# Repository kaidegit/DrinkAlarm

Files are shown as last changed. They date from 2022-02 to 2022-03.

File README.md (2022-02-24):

# 提醒喝水器

本项目致力于复刻[何同学视频](https://www.bilibili.com/video/BV1244y1p7kt)中的智能杯垫，并添加更多的功能。~~才不是因为何同学做的开灯方案太没意义呢~~

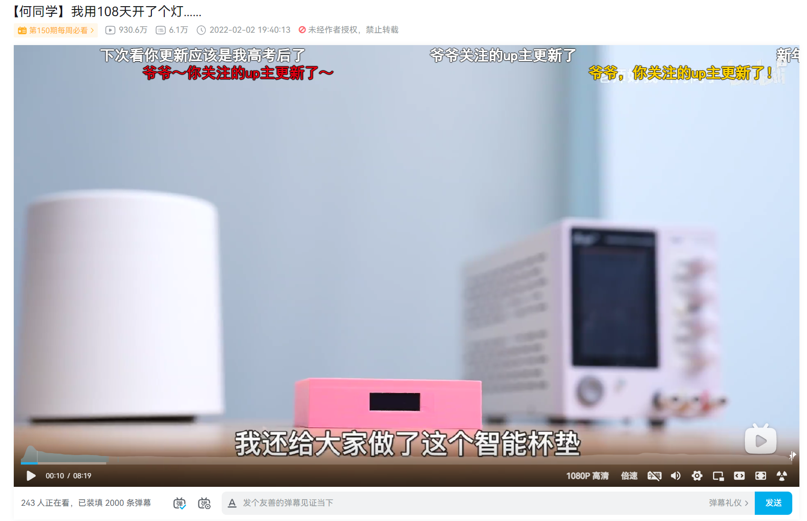
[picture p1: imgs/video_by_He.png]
video_by_He


## 方案设计

* 主芯片使用乐鑫ESP32，能在提供足够的性能的同时提供一个够用的互联网连接

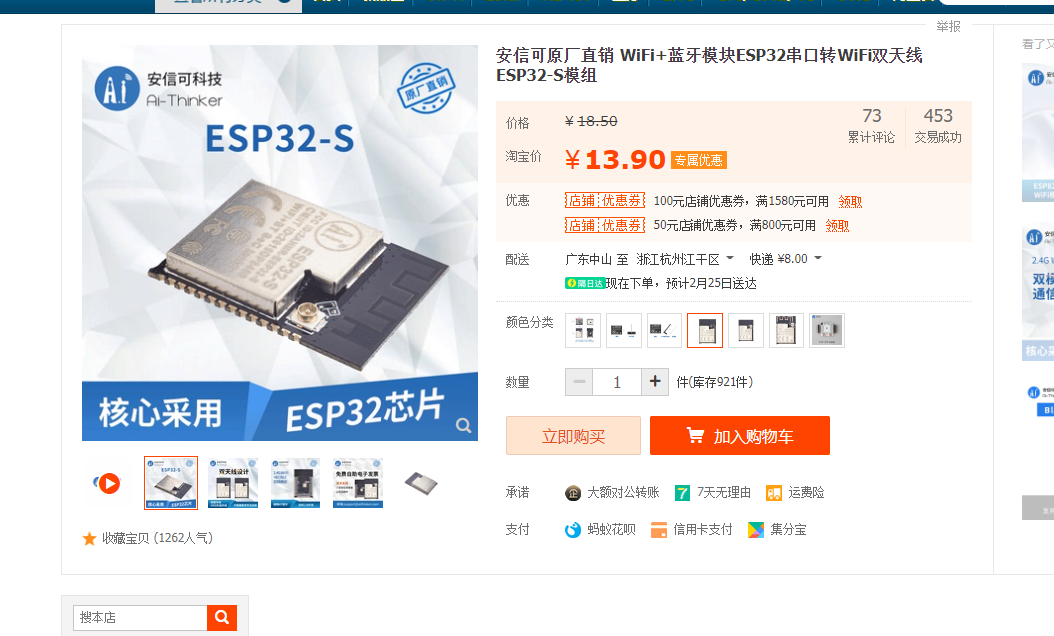
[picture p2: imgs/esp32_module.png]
esp32_module


* 检测杯子存在采用光电传感器，价格低廉，识别准确，美中不足需要在外壳上开孔

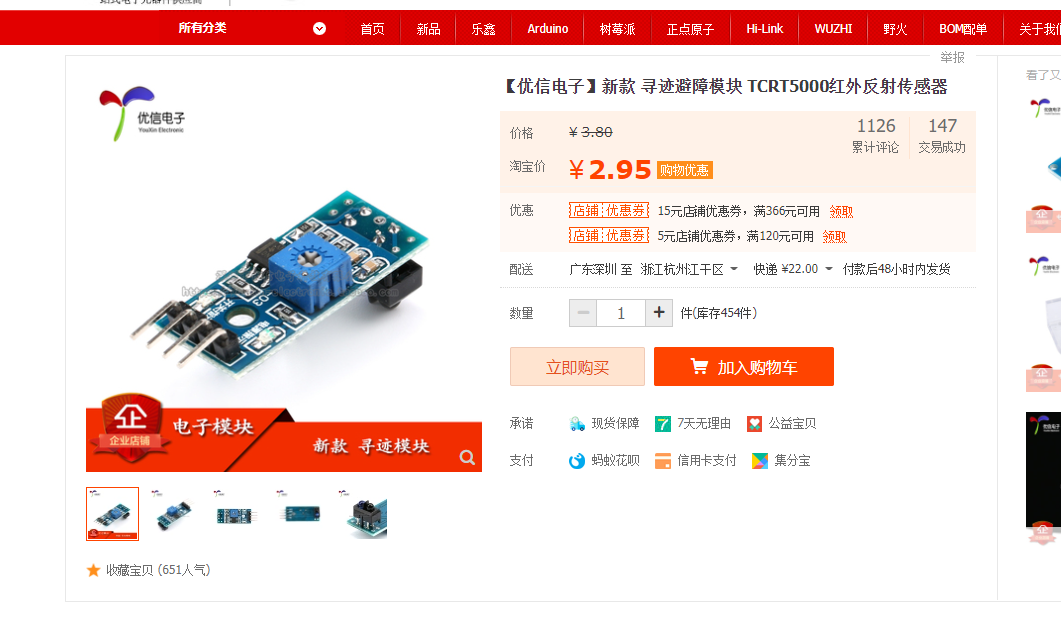
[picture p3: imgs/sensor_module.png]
sensor_module


* 提醒方案采用[Server酱](https://sct.ftqq.com/)的微信推送，同时板载蜂鸣器，可自行修改代码使用

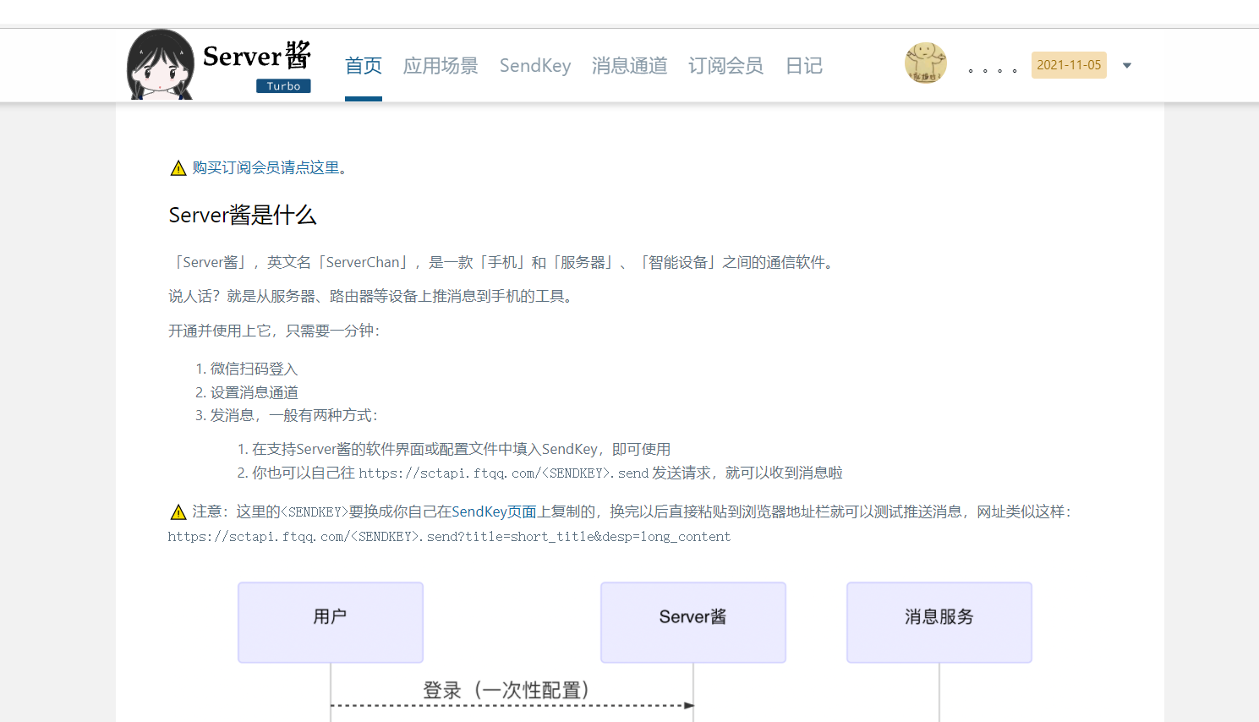
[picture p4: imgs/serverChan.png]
serverChan


* 外壳采用PETG打印而成，可自行选择其他材料以适应盛放开水的杯子

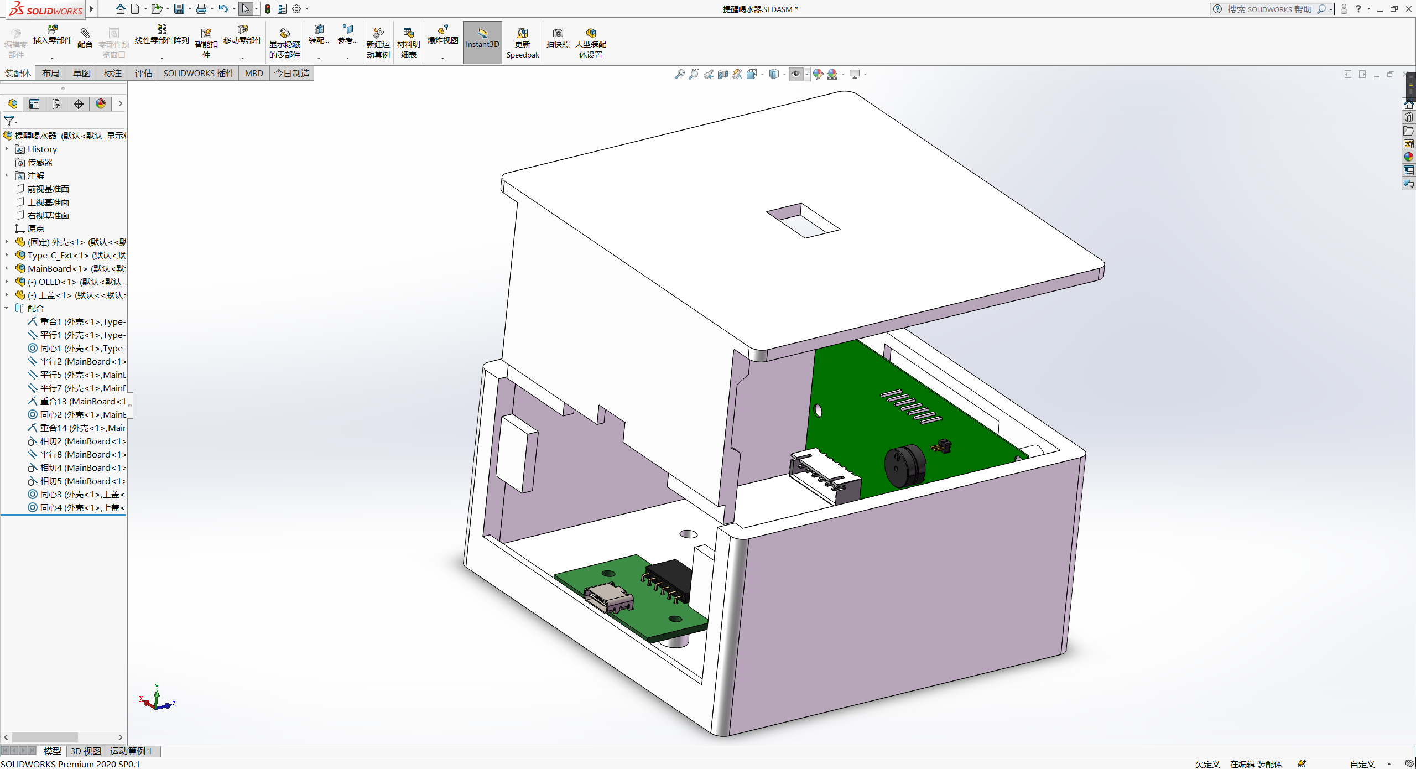
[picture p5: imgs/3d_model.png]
3d_model


## PCB设计

PCB使用Altium Designer和KiCAD设计。由于前后距离略长，PCB分为两块，一块为Type-C小板，一块为主PCB，两者通过杜邦线相连。推荐使用XH2.54系列端子以避免潜在的接触不良。推荐使用长度10或15厘米的线材。

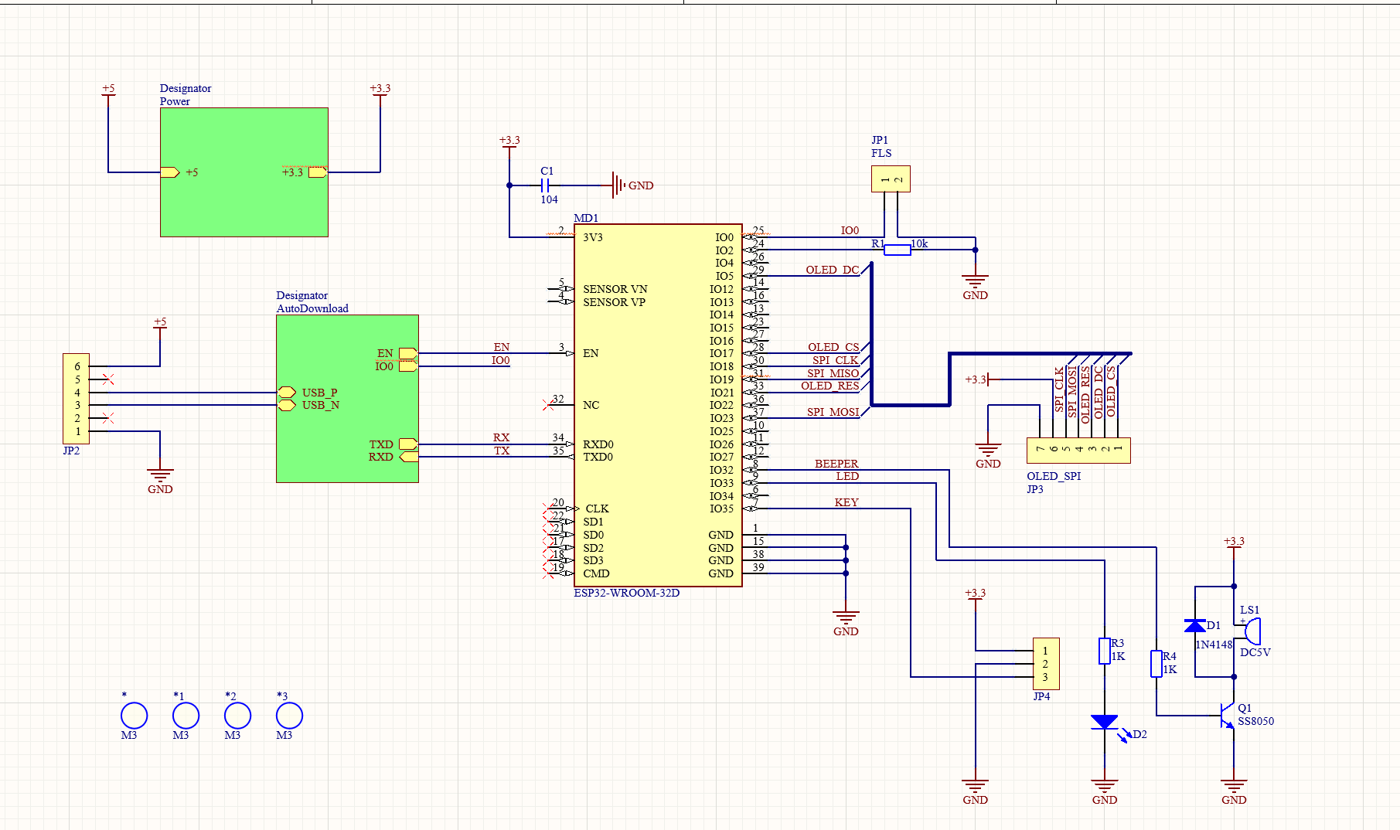
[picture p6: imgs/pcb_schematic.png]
pcb_schematic


## 外壳设计

外壳使用SoildWorks设计（大版本2020）。设计了上盖和底壳，两者通过长螺丝连接。长螺丝推荐使用M3 45mm，其他螺丝推荐使用M3 5mm。对于外壳的修改意见，欢迎提交issue和PR。

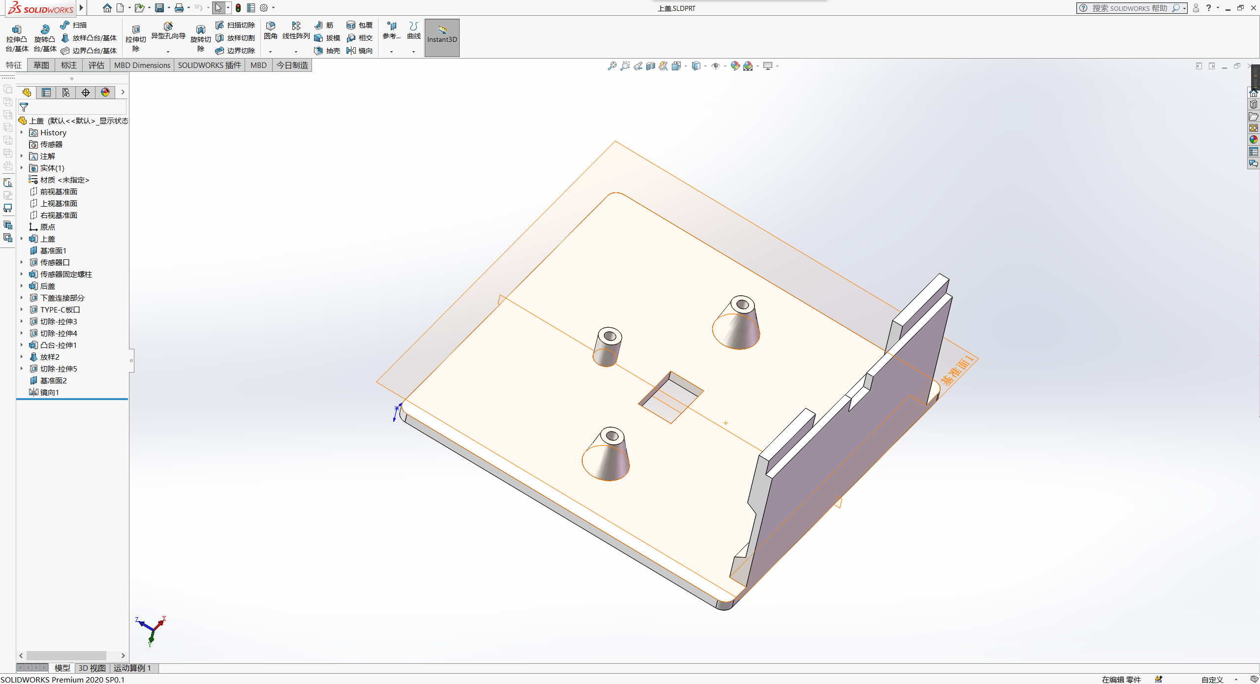
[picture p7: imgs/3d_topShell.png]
3d_topShell


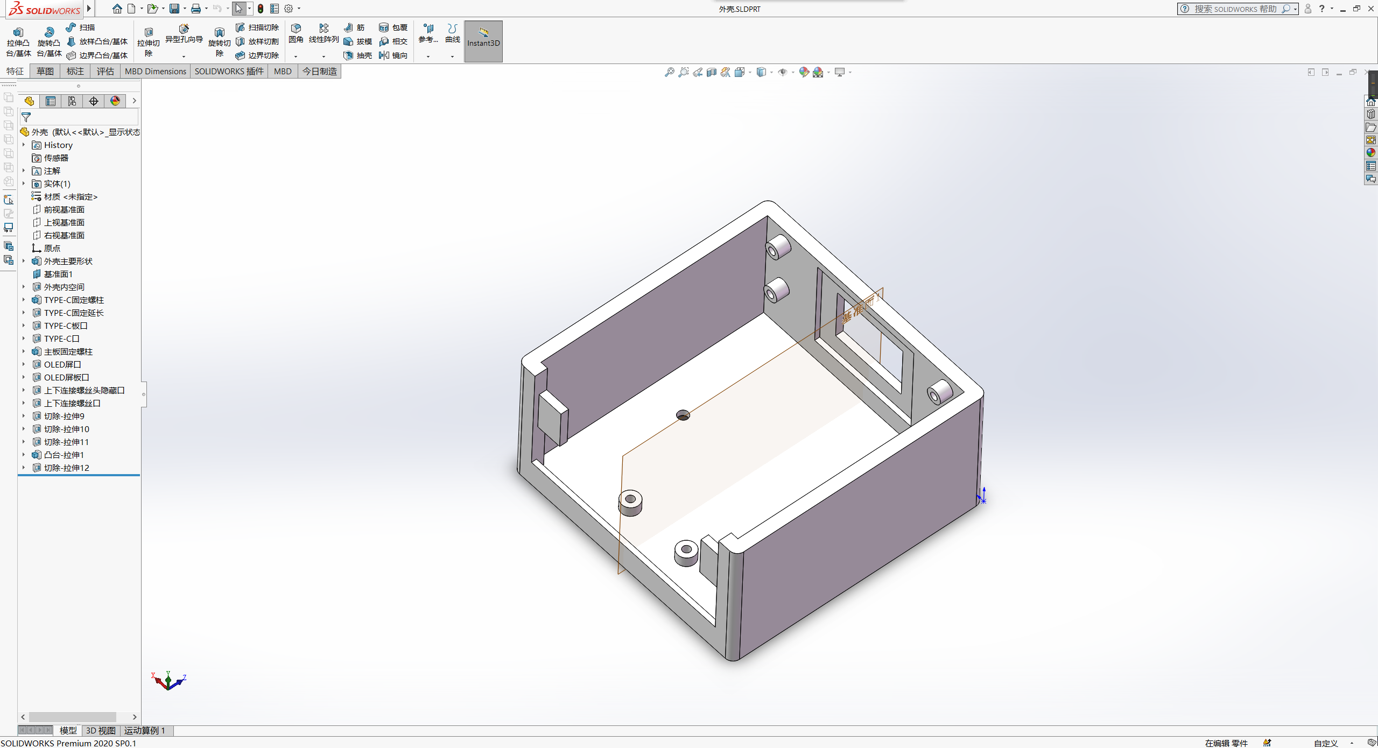
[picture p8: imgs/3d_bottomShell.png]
3d_bottomShell


## 程序设计

程序基于ESP-IDF框架，并使用Arduino as a ESP-IDF component。预计后期将移除。

程序主要功能为设定报警时间，获取联网信息，获取在线时间并显示，计时杯子存在时间并推送等。

主要流程如下：

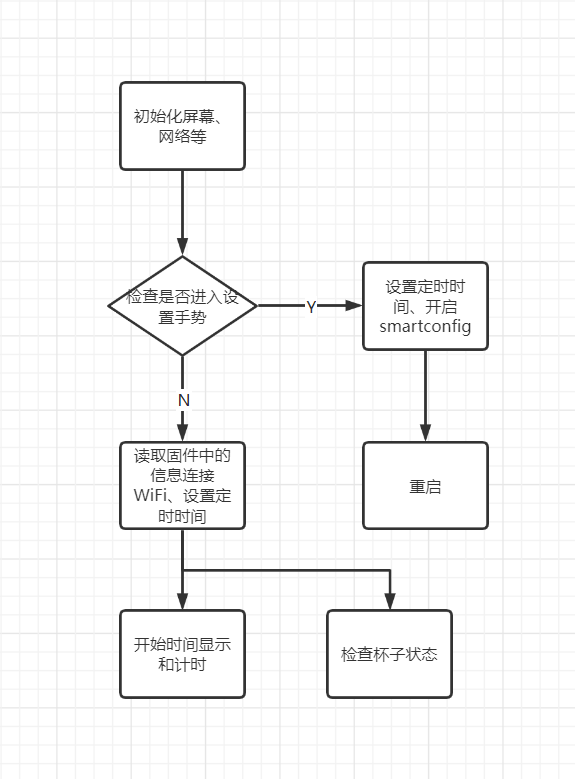
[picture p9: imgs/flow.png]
flow


## 效果图

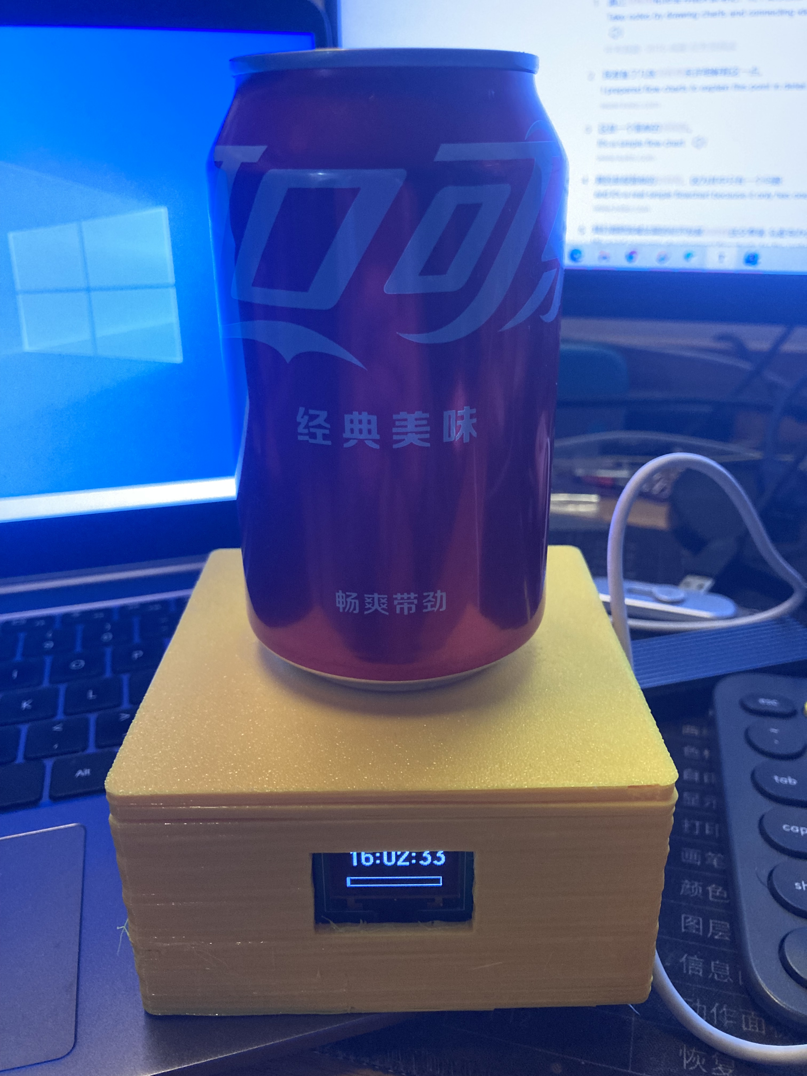
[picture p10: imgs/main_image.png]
main_image


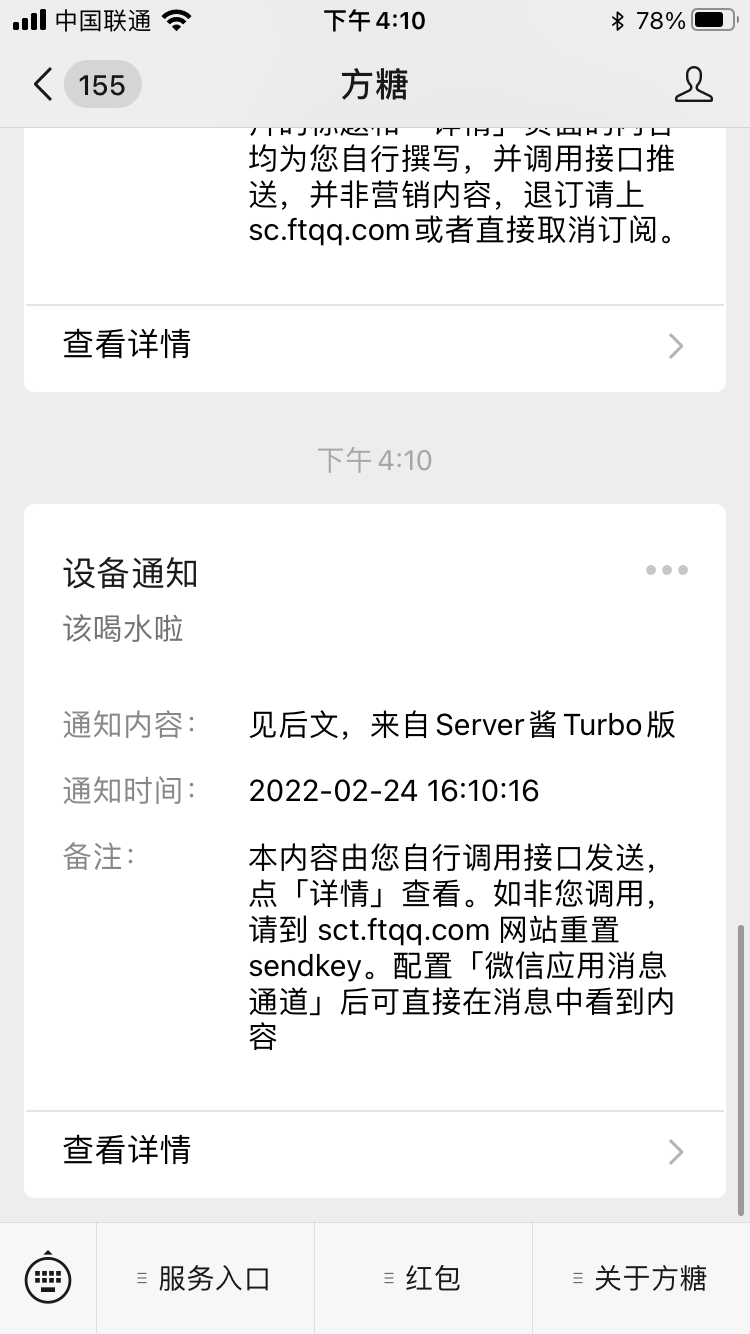
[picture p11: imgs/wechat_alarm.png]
wechat_alarm


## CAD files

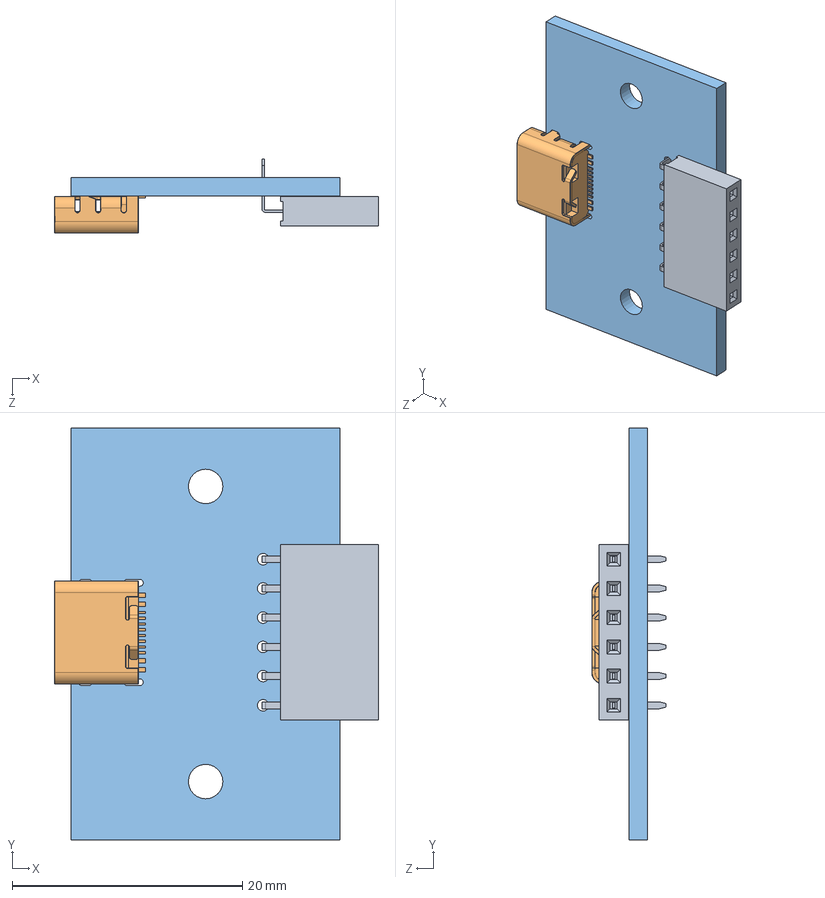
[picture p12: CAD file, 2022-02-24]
3DModel/Type-C_Ext.SLDASM
28.2 x 35.8 x 6.47 mm
SOLID^PinSocket_1x06_P2.54mm_Horizontal_Type-C_Ext(2)_Type-C_Ext
COMPOUND^Type-C_16Pin_ThroughtHole_Type-C_Ext(2)_Type-C_Ext
Type-C_Ext PCB^Type-C_Ext(2)_Type-C_Ext

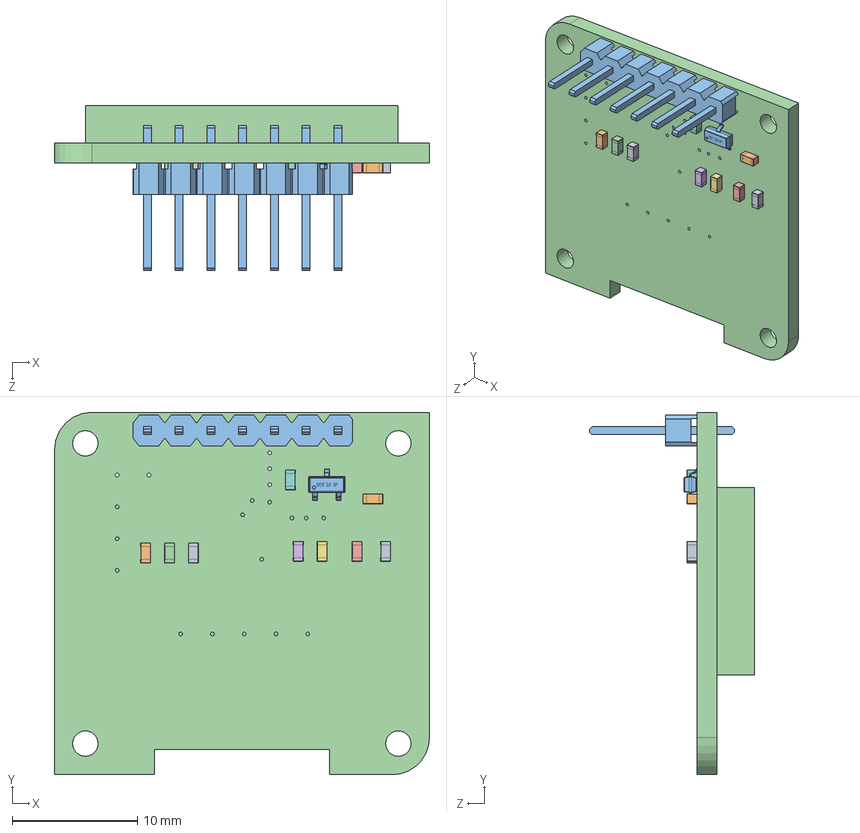
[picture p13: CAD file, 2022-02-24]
3DModel/OLED.SLDASM
30.0 x 29.0 x 13.2 mm
=_[0_1_1_5]^R0603_R5(2)_3D_PCB_7针SPI_2022-02-05_2022-02-05(2)_OLED
=_[0_1_1_5]^R0603_R6(2)_3D_PCB_7针SPI_2022-02-05_2022-02-05(2)_OLED
=_[0_1_1_10]^HDR-M-2.54_1X7_J1_3D_PCB_7针SPI_2022-02-05_2022-02-05(2)_OLED
=_[0_1_1_14]^C0603_C5(2)_3D_PCB_7针SPI_2022-02-05_2022-02-05(2)_OLED
=_[0_1_1_14]^C0603_C2(2)_3D_PCB_7针SPI_2022-02-05_2022-02-05(2)_OLED
=_[0_1_1_14]^C0603_C3(2)_3D_PCB_7针SPI_2022-02-05_2022-02-05(2)_OLED
=_[0_1_1_14]^C0603_C4(2)_3D_PCB_7针SPI_2022-02-05_2022-02-05(2)_OLED
=_[0_1_1_14]^C0603_C7(2)_3D_PCB_7针SPI_2022-02-05_2022-02-05(2)_OLED
=_[0_1_1_14]^C0603_C1(2)_3D_PCB_7针SPI_2022-02-05_2022-02-05(2)_OLED
=_[0_1_1_14]^C0603_C6(2)_3D_PCB_7针SPI_2022-02-05_2022-02-05(2)_OLED
COMPOUND(2)^SOT-23-3_L2.9-W1.3-P1.90-LS2.4-BR_U1(2)_3D_PCB_7针SPI_2022-02-05_2022-02-05(2)_OLED
COMPOUND-0^3D_PCB_7针SPI_2022-02-05_2022-02-05(2)_OLED

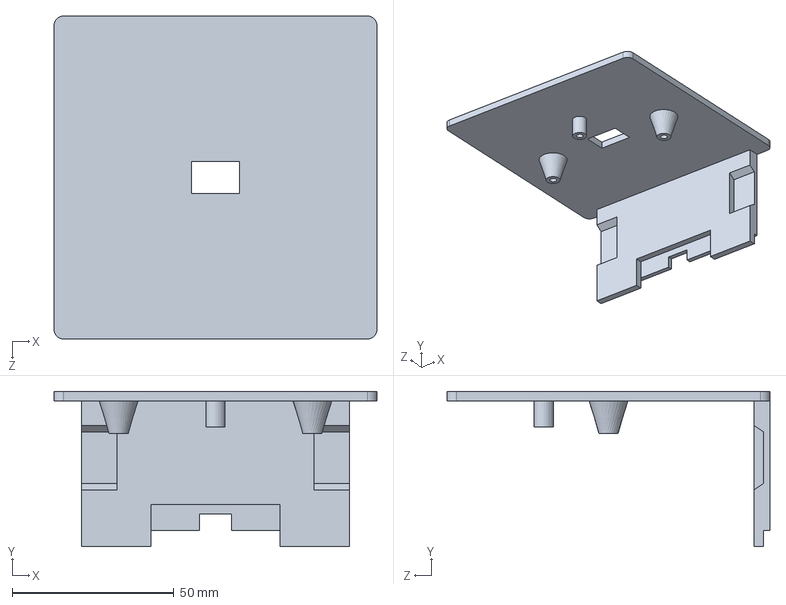
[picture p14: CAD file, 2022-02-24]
3DModel/上盖.SLDPRT
100.0 x 48.0 x 100.0 mm

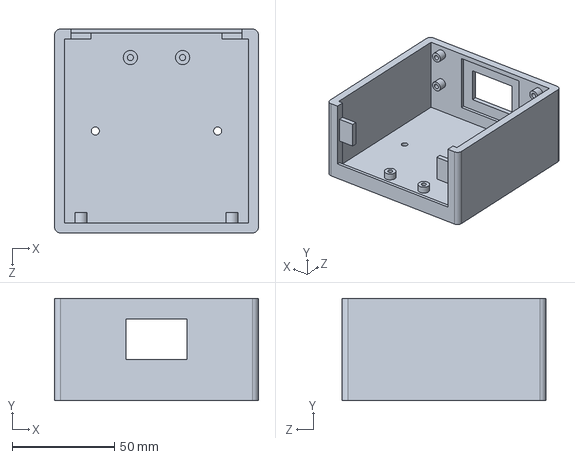
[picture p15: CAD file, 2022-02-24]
3DModel/外壳.SLDPRT
100.0 x 50.0 x 100.0 mm

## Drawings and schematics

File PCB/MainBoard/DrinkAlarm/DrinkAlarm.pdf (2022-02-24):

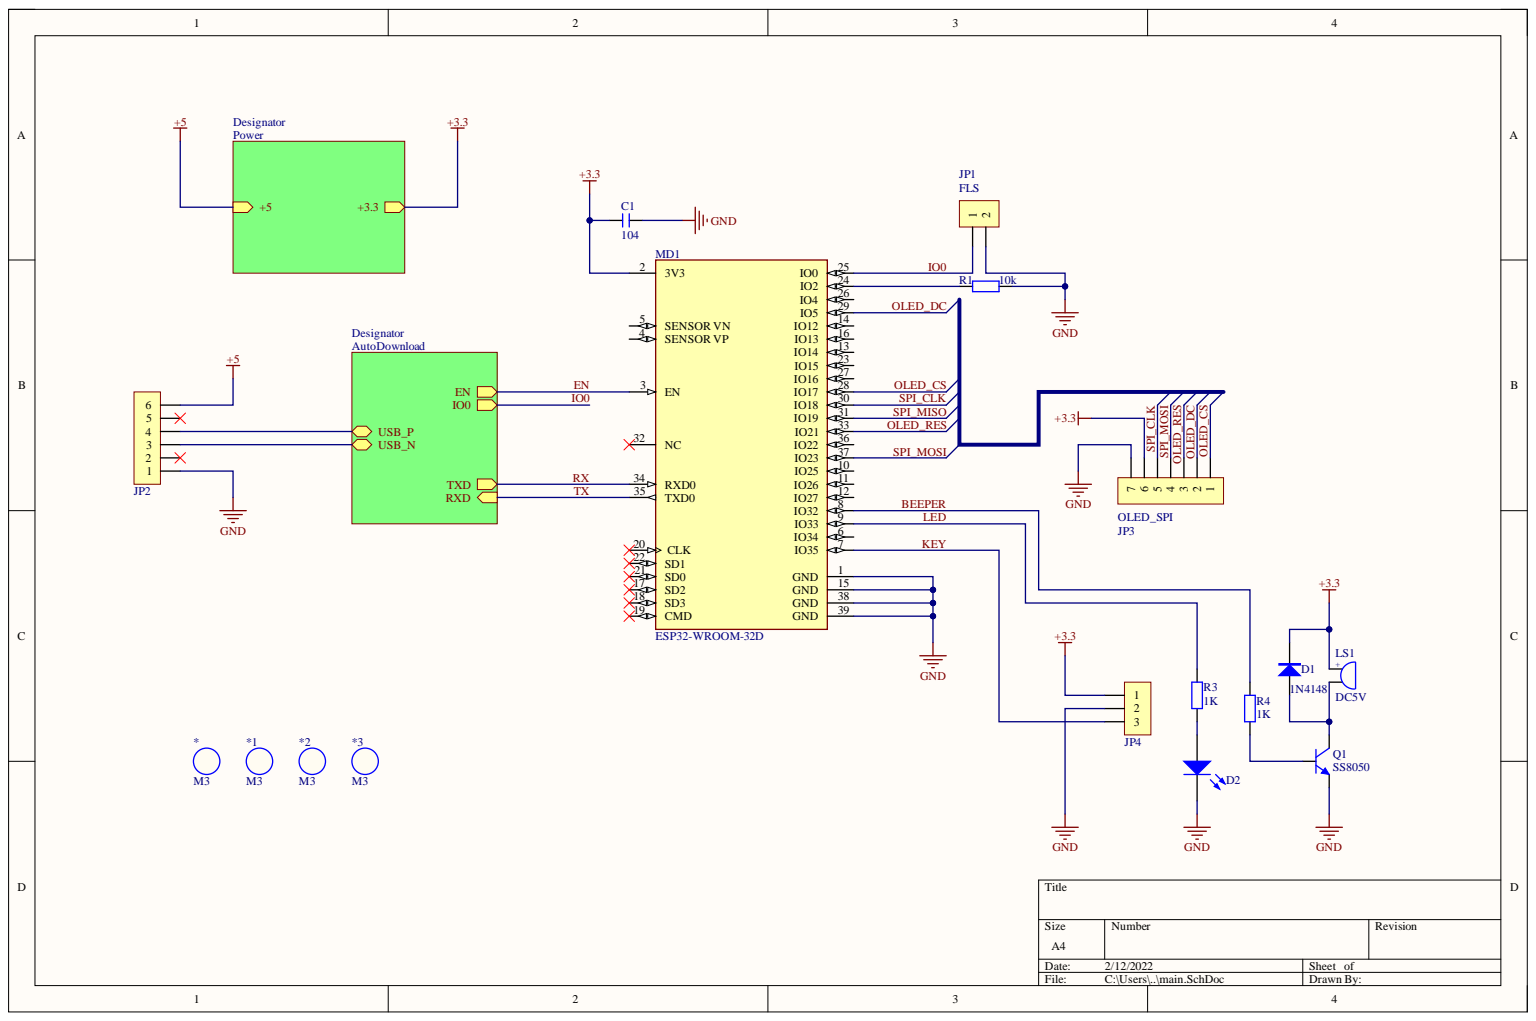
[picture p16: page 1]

9 | L E D O L E D _SP I
6 | J P 3 K E Y

1 5
3 8
3 9

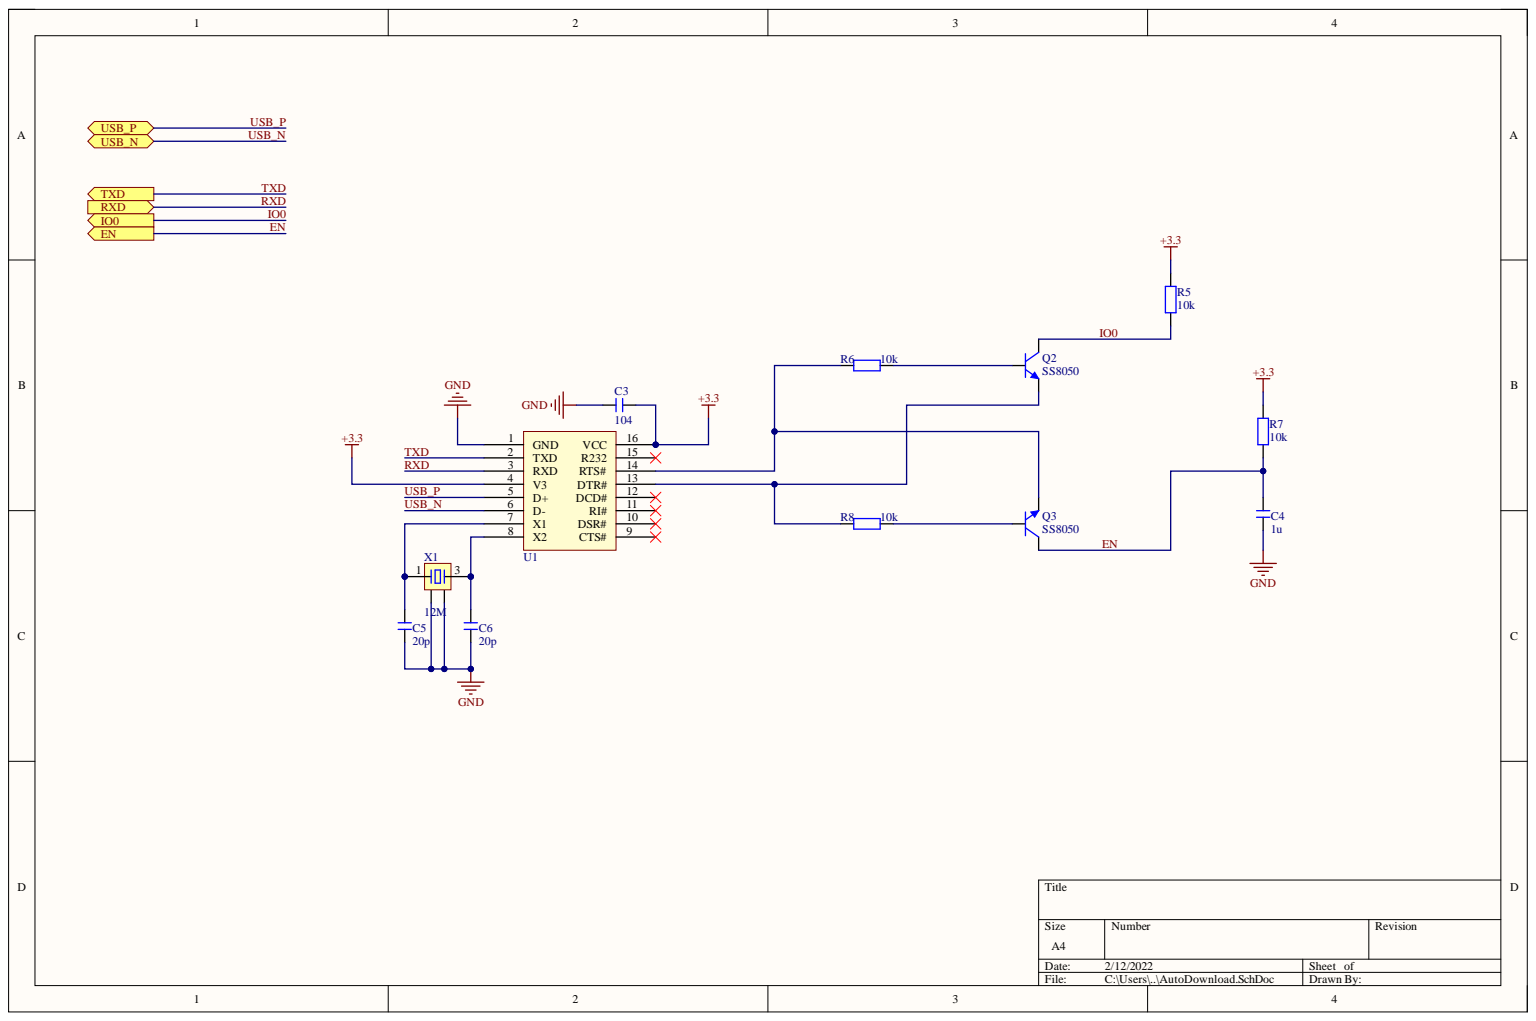
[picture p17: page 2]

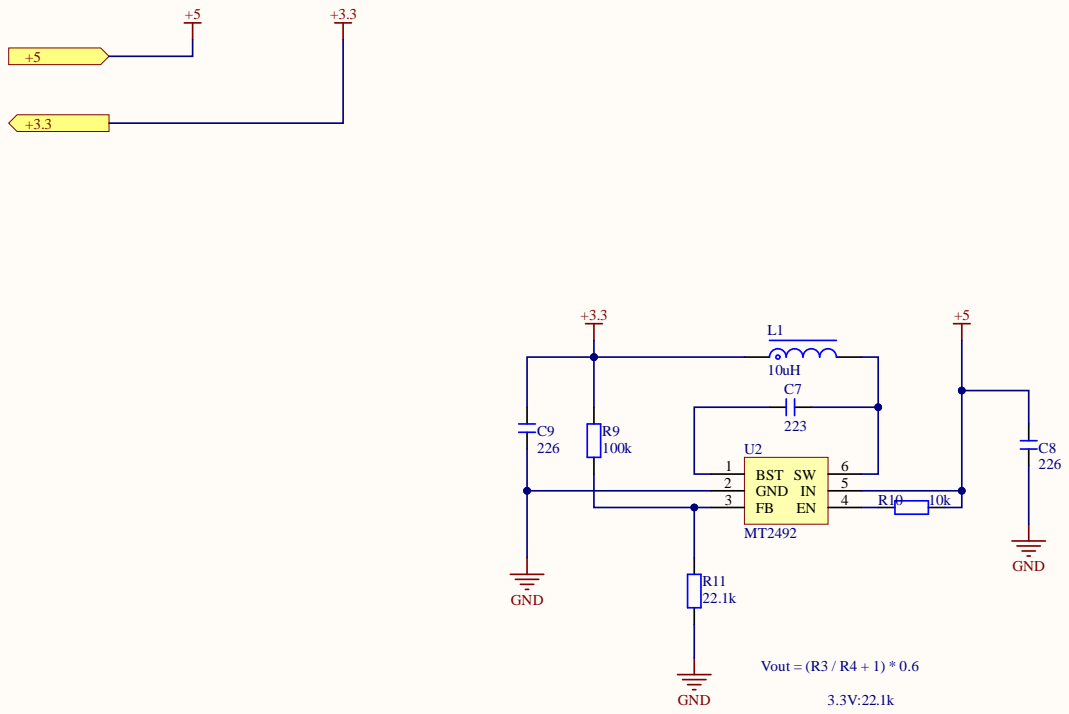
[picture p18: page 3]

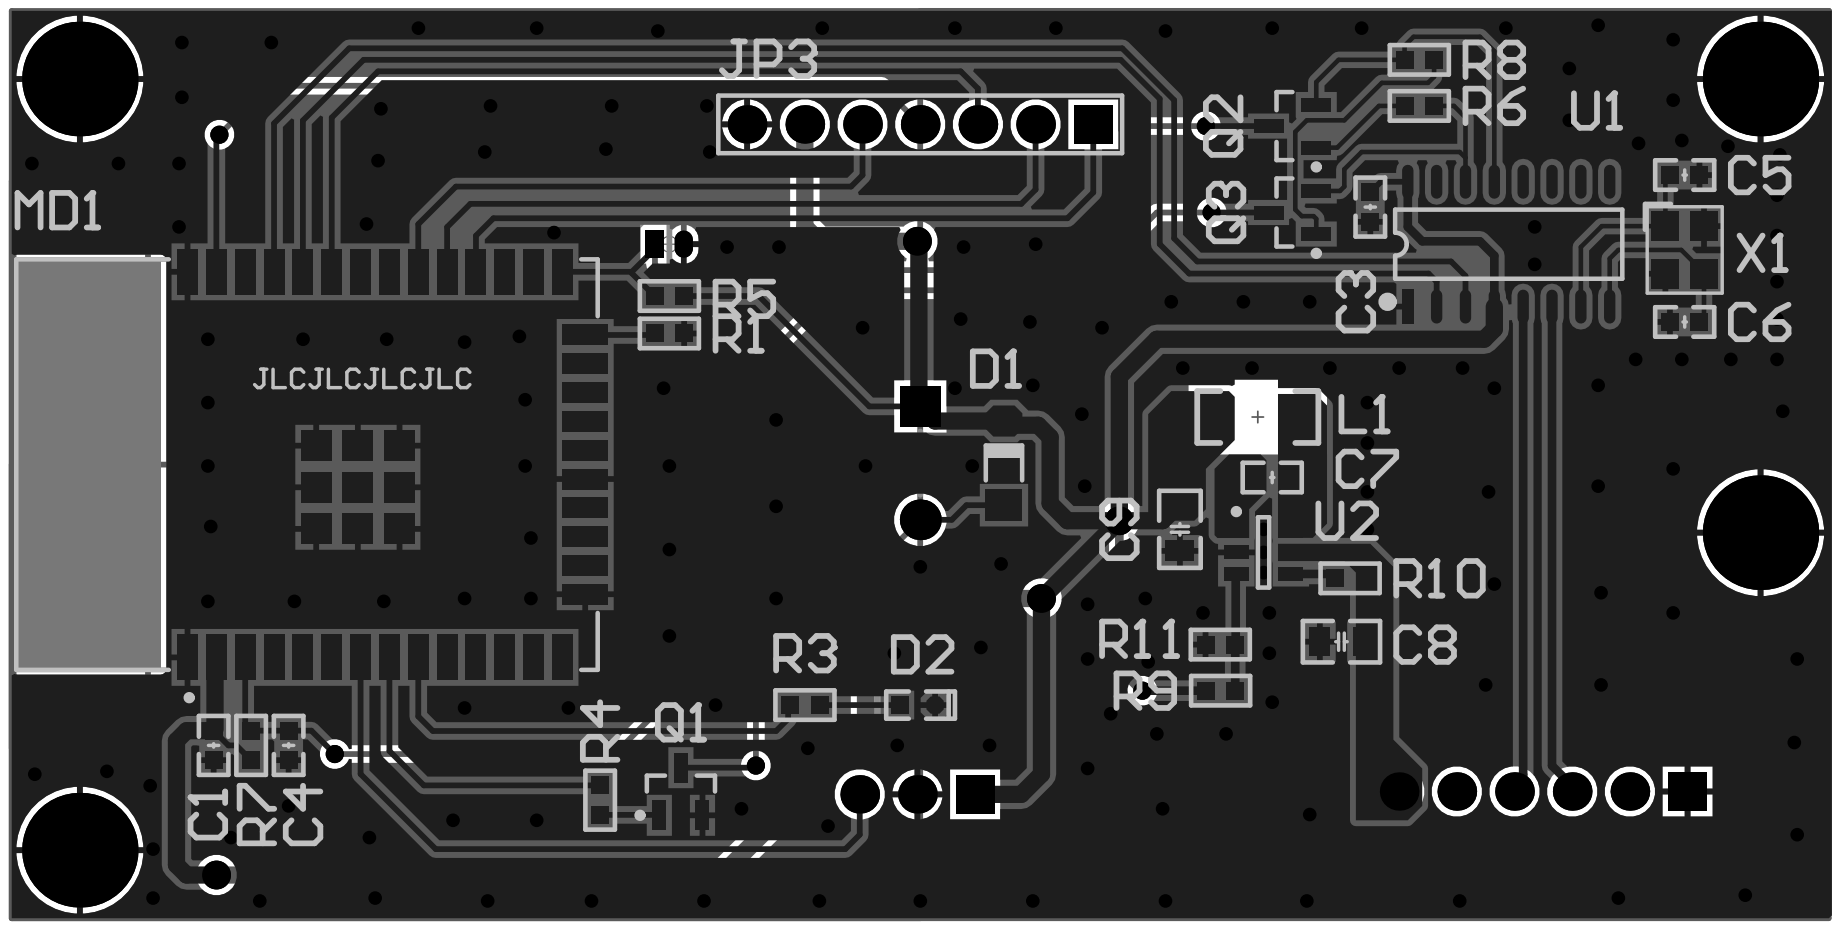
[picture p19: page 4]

Comment | Description | Designator | Footprint | LibRef | Quantity
M3 | 铜柱孔 | [NoValue], *1, *2, *3 | M3 125X200 | M3 | 4
104 | 贴片电容 | C1, C3 | C 0603-L | C | 2
1u | 贴片电容 | C4 | C 0603-L | C | 1
20p | 贴片电容 | C5, C6 | C 0603-L | C | 2
223 | 贴片电容 | C7 | C 0603-L | C | 1
226 | 贴片电容 | C8, C9 | C 0805-L | C | 2
1N4148 | 开关二极管 | D1 | MINI_MELF (LL34) | 1N4148 | 1
LED | 发光二极管 | D2 | LED 0603R | LED | 1
FLS | 2P接插件 | JP1 | HDR1.27-LI-2P | Header 2 | 1
HDR-1X6 | 6P接插件 | JP2 | XH2.54-LI-6P | Header 6 | 1
OLED_SPI | 7P接插件 | JP3 | HDR2.54-M-LI-7P | Header 7 | 1
HDR-1X3 | 3P接插件 | JP4 | XH2.54-LI-3P | Header 3 | 1
10uH | NR磁胶电感 | L1 | L 1206 | L-NR | 1
DC5V | 蜂鸣器 | LS1 | BEEP 5x9x5.5 | BEEP | 1
ESP32-WROOM-32D | WIFI MODULE 32MBITS SPI FLASH | MD1 | FP-ESP32-WROOM-32D-MFG | CMP-194065-000003-1 | 1
SS8050 | 高频放大-NPN型 | Q1, Q2, Q3 | SOT23-3N | 8050-SMD | 3
10k | 贴片电阻 | R1, R5, R6, R7, R8, R10 | R 0603_L | R | 6
1K | 贴片电阻 | R3, R4 | R 0603_L | R | 2
100k | 贴片电阻 | R9 | R 0603_L | R | 1
22.1k | 贴片电阻 | R11 | R 0603_L | R | 1
CH340G | | U1 | sop16_L | CH340G | 1
MT2492 | DC降压芯片 | U2 | SOT23-6N | MP2359 | 1
12M | 4脚无源晶振 | X1 | OSC 3225-4P | XTAL-4P | 1

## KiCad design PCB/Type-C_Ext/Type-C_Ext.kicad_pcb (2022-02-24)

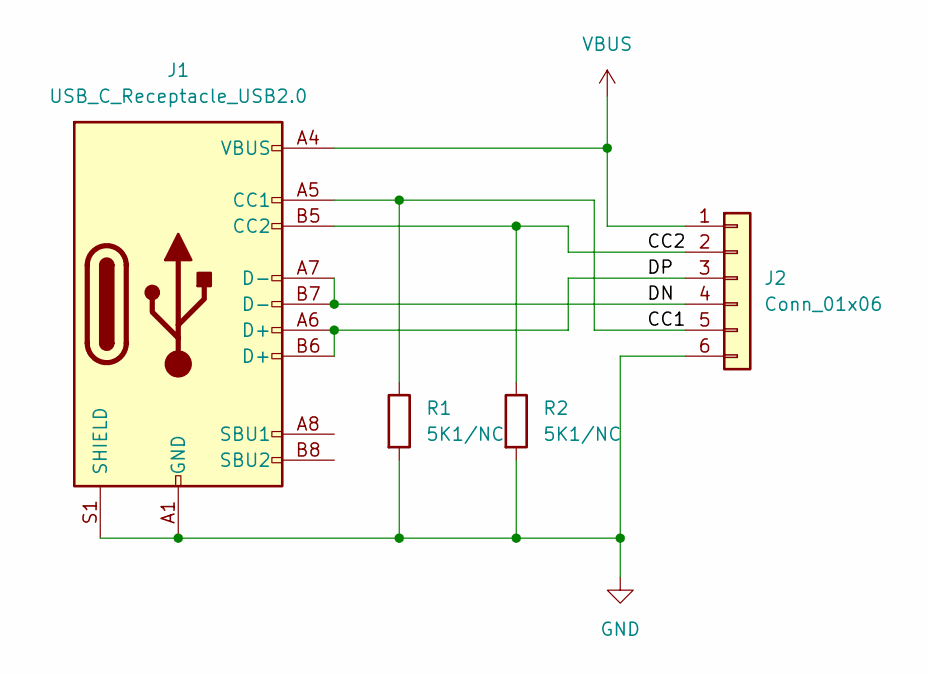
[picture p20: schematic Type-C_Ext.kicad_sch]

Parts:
J1: USB_C_Receptacle_USB2.0; USB_C_Receptacle_HRO_TYPE-C-31-M-12
J2: Conn_01x06; PinSocket_1x06_P2.54mm_Horizontal
R1, R2: 5K1/NC; R_0603_1608Metric_Pad0.98x0.95mm_HandSolder

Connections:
/CC1: J1.A5 (CC1), J2.5, R1.1
/CC2: J1.B5 (CC2), J2.2, R2.1
/DN: J1.A7 (D-), J1.B7 (D-), J2.4
/DP: J1.A6 (D+), J1.B6 (D+), J2.3
GND: J1.A1 (GND), J1.A12 (GND), J1.B1 (GND), J1.B12 (GND), J1.S1 (SHIELD), J2.6, R1.2, R2.2
VBUS: J1.A4 (VBUS), J1.A9 (VBUS), J1.B4 (VBUS), J1.B9 (VBUS), J2.1

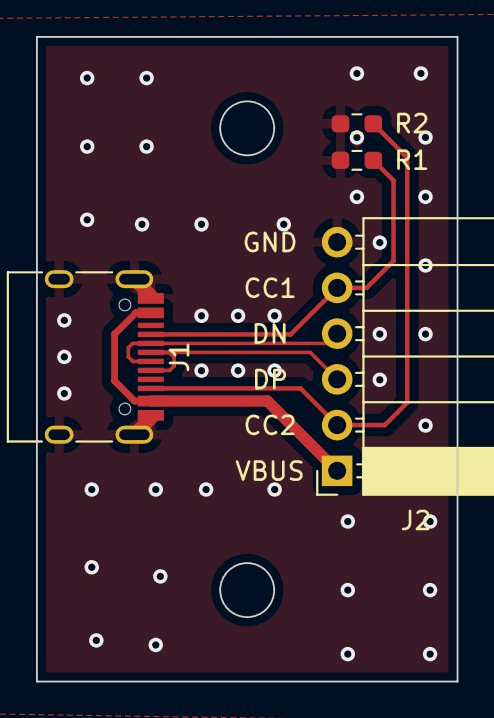
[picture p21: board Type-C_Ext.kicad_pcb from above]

Board: 2 copper layers, 23.4 x 35.8 mm, 4 parts (0 on the bottom side), 6 nets.

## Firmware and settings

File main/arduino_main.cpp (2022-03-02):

//
// Created by yekai on 2022/2/12.
//

#include "arduino_main.h"
#include <nvs_flash.h>
#include <esp_log.h>
#include "esp_task_wdt.h"
#include "wifi_smartconfig.h"
#include "alarm.h"
#include "time_sync.h"
#include "peripheral_init.h"
#include "u8g2.h"
#include "u8g2_port.h"
#include "oled.h"

bool isAlarmOn = false;
bool isAlarm = false;
uint16_t alarmStartTime;

#define delay(_ms) vTaskDelay((_ms) / portTICK_RATE_MS);

void setup() {
    ESP_ERROR_CHECK(nvs_flash_init());
    LED_GPIO_Init();
    SENSOR_GPIO_Init();
    initialise_wifi();
    U8G2_Init();

    // 启动检查手势来进入设置，设置完后重启
    settings_action_catch();
    // 尝试使用flash中信息连接WiFi，读不到信息则进入smartconfig
    if (connect_wifi_from_flash() != ESP_OK) {
        start_smartconfig();
    }
    //读flash中的闹钟时长
    read_alarm_from_flash();
    // 同步时间
    sync_time_sntp();

    xTaskCreate(
            OLED_Time_Task,
            "oled_time_task",
            4096,
            nullptr,
            3,
            nullptr
    );
}

void loop() {
    static int state = 1;
    if (state != gpio_get_level((gpio_num_t)SENSOR_Pin)) {
        delay(10);
        if (state != gpio_get_level((gpio_num_t)SENSOR_Pin)) {
            state = gpio_get_level((gpio_num_t)SENSOR_Pin);
            if (IS_CUP_ON()) {
                // should set alarm
                ESP_LOGI("sensor", "sensor get low");
                isAlarmOn = true;
                alarmStartTime = get_time(nullptr,nullptr,nullptr);
            } else {
                // should reset alarm
                ESP_LOGI("sensor", "sensor get high");
                isAlarmOn = false;
                isAlarm = false;
            }
        }
    }
    delay(10);
}

// 上电后杯子存在，5秒内杯子移开，移开后5秒内杯子放回，则进入
#define WAIT_TIME_MS 5000 // 5s
#define WAIT_COUNT (WAIT_TIME_MS/10)
#define COUNT2TIME(_c) ((_c)/100)

void settings_action_catch() {
    // 杯子存在检测
    if (IS_CUP_ON()) {
        delay(10);
        if (IS_CUP_ON()) {
            // 5秒内杯子移开检测
            uint16_t count = 0;
            while (count++ < WAIT_COUNT) {
                if (count % 100 == 0) {
                    OLED_ShowWaitToSet(COUNT2TIME(WAIT_COUNT - count) + 1, false);
                }
                esp_task_wdt_reset();
                delay(10);
                if (IS_CUP_OFF()) {
                    delay(10);
                    if (IS_CUP_OFF()) {
                        // 5秒内杯子放回检测
                        count = 0;
                        while (count++ < WAIT_COUNT) {
                            if (count % 100 == 0) {
                                OLED_ShowWaitToSet(COUNT2TIME(WAIT_COUNT - count) + 1, true);
                            }
                            esp_task_wdt_reset();
                            delay(10);
                            if (IS_CUP_ON()) {
                                delay(10);
                                if (IS_CUP_ON()) {
                                    // 进入设置
                                    ESP_LOGI("settings", "entry settings");
                                    start_smartconfig();
                                    set_alarm_time();
                                    count = WAIT_COUNT;
                                }
                            }
                        }
                    }
                }
            }
        }
    }
}

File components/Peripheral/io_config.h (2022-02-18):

//
// Created by yekai on 2022/2/12.
//

#ifndef MAIN_IO_CONFIG_H
#define MAIN_IO_CONFIG_H

// LED & Sensor Pins
#define LED_Pin 33
#define SENSOR_Pin 35

// OLED Pins
#define OLED_SDA_Pin 23
#define OLED_SCL_Pin 18
#define OLED_RES_Pin 21
#define OLED_DC_Pin 5
#define OLED_CS_Pin 17
#define OLED_SPI_HOST VSPI_HOST

// Cup state
#include "hal/gpio_types.h"
#include "driver/gpio.h"
#define IS_CUP_ON() (gpio_get_level((gpio_num_t)SENSOR_Pin) == 0)
#define IS_CUP_OFF() (gpio_get_level((gpio_num_t)SENSOR_Pin) == 1)

#endif //MAIN_IO_CONFIG_H

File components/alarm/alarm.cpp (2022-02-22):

//
// Created by yekai on 2022/2/15.
//

#include <nvs.h>
#include <esp_task_wdt.h>
#include <esp_log.h>
#include "alarm.h"
#include "alarm_url.h"
#include "oled.h"
#include "io_config.h"

#include "lwip/err.h"
#include "lwip/sockets.h"
#include "lwip/sys.h"
#include "lwip/netdb.h"
#include "lwip/dns.h"

// 闹钟时长，单位分钟
uint8_t alarm_time;

static char *TAG = (char *) "alarm";

static esp_err_t save_alarm_to_flash() {
    nvs_handle_t save_alarm_nvs_handle;
    static char *TAG = (char *) "NSV save alarm";

    if (nvs_open("nvs", NVS_READWRITE, &save_alarm_nvs_handle) != ESP_OK) {
        ESP_LOGE(TAG, "open nvs fail");
        nvs_close(save_alarm_nvs_handle);
        return ESP_ERR_NVS_NOT_FOUND;
    }

    ESP_LOGI(TAG, "open nvs success,saving.....");
    if (nvs_set_u8(save_alarm_nvs_handle, "alarm", alarm_time) != ESP_OK) {
        ESP_LOGE(TAG, "nvs save alarm fail");
        nvs_close(save_alarm_nvs_handle);
        return ESP_ERR_NVS_NOT_FOUND;
    }

    ESP_LOGI(TAG, "saved alarm:%d", (int) alarm_time);
    nvs_close(save_alarm_nvs_handle);
    return ESP_OK;
}

esp_err_t read_alarm_from_flash() {
    nvs_handle_t get_alarm_nvs_handler;
    static char *TAG = (char *) "NSV read alarm";

    if (nvs_open("nvs", NVS_READONLY, &get_alarm_nvs_handler) != ESP_OK) {
        ESP_LOGE(TAG, "nvs open fail");
        nvs_close(get_alarm_nvs_handler);
        return ESP_ERR_NVS_NOT_FOUND;
    }

    if (nvs_get_u8(get_alarm_nvs_handler, "alarm", &alarm_time) != ESP_OK) {
        ESP_LOGE(TAG, "nvs get alarm fail");
        nvs_close(get_alarm_nvs_handler);
        return ESP_ERR_NVS_NOT_FOUND;
    }

    ESP_LOGI(TAG, "read alarm:%d", alarm_time);
    nvs_close(get_alarm_nvs_handler);
    return ESP_OK;
}

const uint8_t alarm_time_setting_list[] = {
        5, 15, 30, 60, 90, 120, 240
};
#define ALARM_TIME_LIST_LENGTH 7

// 调时间逻辑：进入设置时杯子为放回状态，抬起一次下一个设定时间，放回20秒后为设定时间。
void set_alarm_time() {
    uint8_t set_time_index = 0;
    uint16_t count = 0;

    read_alarm_from_flash();
    for (auto i = 0; i < ALARM_TIME_LIST_LENGTH; i++) {
        if (alarm_time == alarm_time_setting_list[i]) {
            set_time_index = i;
            break;
        }
    }
    OLED_ShowTimeSet(alarm_time_setting_list[set_time_index]);
    while (count++ < 2000) {
        esp_task_wdt_reset();
        vTaskDelay(10 / portTICK_RATE_MS);
        // 检测移开
        if (IS_CUP_OFF()) {
            vTaskDelay(10 / portTICK_RATE_MS);
            if (IS_CUP_OFF()) {
                set_time_index++;
                if (set_time_index >= ALARM_TIME_LIST_LENGTH) {
                    set_time_index = 0;
                }
                OLED_ShowTimeSet(alarm_time_setting_list[set_time_index]);
                ESP_LOGI(TAG, "select %d", alarm_time_setting_list[set_time_index]);
            }
        }
        // 等待放回（移开结束）
        while (IS_CUP_OFF()) {
            esp_task_wdt_reset();
            vTaskDelay(10 / portTICK_RATE_MS);
        }
    }
    alarm_time = alarm_time_setting_list[set_time_index];
    save_alarm_to_flash();
    vTaskDelay(1000 / portTICK_RATE_MS);
    esp_restart();
}

void alarm_callback() {
    gpio_set_level((gpio_num_t) LED_Pin, 1);
    xTaskCreate(
            http_get_task,
            "http_get_task",
            4096,
            nullptr,
            3,
            nullptr
    );
}

// defines' format examples (ServerChan:) are as follows:
// #define WEB_URL "sctapi.ftqq.com"
// #define WEB_PATH "/<your_sendkey>?title=<your_title>&desp=<long_content>"
//
// more informations about ServerChan:https://sct.ftqq.com/
#ifndef WEB_URL
    #error Please set alarm url string with define
#endif
#ifndef WEB_PATH
    #error Please set alarm url string with define
#endif
#define WEB_PORT "80"
static const char *REQUEST =
        "GET " WEB_PATH " HTTP/1.0\r\n"
        "Host: " WEB_URL":" WEB_PORT"\r\n"
        "User-Agent: esp-idf/1.0 esp32\r\n"
        "\r\n";

void http_get_task(void *pvParameters) {
    struct addrinfo hints = {};
    hints.ai_family = AF_INET;
    hints.ai_socktype = SOCK_STREAM;
    struct addrinfo *res;
    struct in_addr *addr;
    int s, r(0);
    char recv_buf[64];

    int err = getaddrinfo((const char *) WEB_URL, WEB_PORT, &hints, &res);

    if (err != 0 || res == nullptr) {
        ESP_LOGE(TAG, "DNS lookup failed err=%d res=%p", err, res);
        vTaskDelete(nullptr);
    }

    /* Code to print the resolved IP.

       Note: inet_ntoa is non-reentrant, look at ipaddr_ntoa_r for "real" code */
    addr = &((struct sockaddr_in *) res->ai_addr)->sin_addr;
    ESP_LOGI(TAG, "DNS lookup succeeded. IP=%s", inet_ntoa(*addr));

    s = socket(res->ai_family, res->ai_socktype, 0);
    if (s < 0) {
        ESP_LOGE(TAG, "... Failed to allocate socket.");
        freeaddrinfo(res);
        vTaskDelete(nullptr);
    }
    ESP_LOGI(TAG, "... allocated socket");

    if (connect(s, res->ai_addr, res->ai_addrlen) != 0) {
        ESP_LOGE(TAG, "... socket connect failed errno=%d", errno);
        close(s);
        freeaddrinfo(res);
        vTaskDelete(nullptr);
    }

    ESP_LOGI(TAG, "... connected");
    freeaddrinfo(res);

    if (write(s, REQUEST, strlen(REQUEST)) < 0) {
        ESP_LOGE(TAG, "... socket send failed");
        close(s);
        vTaskDelete(nullptr);
    }
    ESP_LOGI(TAG, "... socket send success");

    struct timeval receiving_timeout = {};
    receiving_timeout.tv_sec = 5;
    receiving_timeout.tv_usec = 0;
    if (setsockopt(s, SOL_SOCKET, SO_RCVTIMEO, &receiving_timeout,
                   sizeof(receiving_timeout)) < 0) {
        ESP_LOGE(TAG, "... failed to set socket receiving timeout");
        close(s);
        vTaskDelete(nullptr);
    }
    ESP_LOGI(TAG, "... set socket receiving timeout success");

    /* Read HTTP response */
    do {
        bzero(recv_buf, sizeof(recv_buf));
        r = read(s, recv_buf, sizeof(recv_buf) - 1);
        for (int i = 0; i < r; i++) {
            putchar(recv_buf[i]);
        }
    } while (r > 0);

    ESP_LOGI(TAG, "... done reading from socket. Last read return=%d errno=%d.", r, errno);
    close(s);
    ESP_LOGI(TAG, "Http Request done");
    gpio_set_level((gpio_num_t) LED_Pin, 0);
    vTaskDelete(nullptr);
}

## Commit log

2022-02-12 init arduino in idf
2022-02-18 use u8g2 to replace lvgl
    [arduino_main.cpp]
2022-02-18 写完了大部分的逻辑
2022-02-18 差不多完工啦
2022-02-22 添加到达定时时间发送http.get的功能
2022-02-24 add 3d models & pcbs
    [AutoDownload.SchDoc, DrinkAlarm.PrjPcb, OLED.SLDASM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]
2022-03-02 remove arduino component dependency
